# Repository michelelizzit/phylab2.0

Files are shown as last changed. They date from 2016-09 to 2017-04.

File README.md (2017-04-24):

# [PhyLab 2.0](https://lizzit.it/phylab)

More details available at https://lizzit.it/phylab

## General description
PhyLab is an open-source, modular system; it makes laboratory experience more interesting simplifying the understanding of science and physics.  
It has been created for school laboratories; it collects and processes experimental data at an incredibly high rate, makes plots and sends them to connected smartphones and other devices. It is composed of a series of collecting-transmitting Arduino-based units equipped with sensors; these deliver the data to the RaspberryPi-based main unit that produces real-time plots.  
This system can collect different types of data (temperature, humidity, speed…), limited only to the sensors available.

## Hardware
The main unit needs to be a RaspberryPI 1, 2 or 3.  
Each transmitting module sends data to the main unit either via an nRF24L01+ module or via USB.
The data is then saved on the main unit and sent to all the connected clients.  
The main unit can also act as a web server, and as a WiFi hotspot, this allows the system to be transported easily.  
It was designed for physics experiments at school, in a physics laboratory, and from that the name PhyLab 2.0
Each transmitting unit is usually based on an Arduino, connected with a sensor and an nRF24L01+ module but a transmitting unit can be made with any microcontroller and any sensor;  
### PhyLab PCBs
We designed two PhyLab PCBs, one that allows an nRF24L01+ module to be easily connected to the RaspberryPi and one that allows to easily build a transmitting unit; more details are available at https://lizzit.it/phylab/  





### Build it yourself
#### Main unit
For the main unit a RaspberryPI and an nRF24L01+ module are required; a DS1307 RTC is highly recommended since it allows the system to work even without wired internet connection; a reliable time, obtained either via NTP or via an RTC, is fundamental for the system to properly store data on the internal memory.  
  
The easiest way to build the main unit is to use a PhyLab 2.0 RaspberryPI module; it allows the nRF24L01+ to be easily connected to the RaspberryPI with no additional wiring needed.  
  
Building a unit without a PhyLab 2.0 RaspberryPI module is also possible.  
The RTC module shall be connected to I2C pins on the P1 header of the RaspberryPI.  
The nRF24L01+ module shall be connected to the RaspberryPI as shown on the diagram under /pcb; adding capacitor between VCC and GND may be useful to smooth current peaks of the nRF24L01+, which may cause system crashes.  
PhyLab 2.0 RaspberryPI module already includes capacitors between VCC and GND lines.  
#### Transmitting units
The easiest way to build a transmitting unit is to use a PhyLab 2.0 experiment module but a trasmitting unit can be also built easily with an Arduino, an nRF24L01+ module and a sensor.  
The nRF24L01+ shall be wired to the Arduino as follows:  

| nRF24L01+ pin  | Arduino pin |
| --- | --- |
| CE | pin 8 |
| CSN | pin 7 |
| MOSI | pin 11  |
| MISO | pin 12  |
| SCK | pin 13  |
| IRQ | N/C |
| VCC | 3.3v |
| GND | GND |

## Software
A pre-built image for RaspberryPI 3 is available, it includes all the software required on the server and in addition it creates a WiFi hotspot; this is the easiest way to set up a complete PhyLab 2.0 system.  
It is based on PhyLab OS, a minimal Linux distribution including a kernel build with just the modules required for PhyLab 2.0 to run.  
This allows PhyLab 2.0 to boot in just 5 seconds and to work out of the box with no setup needed.  
It is especially useful during physics lessons because it allows every student to see the plot and download the data from their smartphones.  

The pre-built image also includes a DNS and DHCP server (dnsmasq) that allows each device to connect easily and display the chart by going to http://phy.lab/  

Software for some experiments we have developed (humidity, acceleration and voltage) has been released, it can be uploaded either on a PhyLab 2.0 module or on an Arduino board.  

## Online demo

Demo version with random data available at: https://lizzit.it/phylab/demo/  
The demo version just shows the web interface, plotting random data, and is not connected to any sensor.






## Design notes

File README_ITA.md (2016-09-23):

# [PhyLab 2.0] (https://lizzit.it/phylab)

More details available at https://lizzit.it/phylab

##General description
PhyLab 2.0 è un sistema modulare e open source per l’acquisizione e l’elaborazione di dati; rende l'esperienza di laboratorio accattivante, facilita l'apprendimento della fisica laboratoriale.  
Acquisisce dati in maniera automatica, anche a frequenza elevata. È composto da unità di acquisizione-trasmissione (basate su Arduino) collegate a uno o più sensori; esse inviano i dati via wireless all’unità centrale (RaspberryPI) che li elabora in grafici. I dati e i grafici sono visualizzabili in tempo reale anche su smartphone. Può acquisire diversi tipi di dati (temperatura, umidità, forza…).  

##Hardware
L’unità centrale è basata su RaspberryPI versione 1, 2 o 3.
Ogni modulo trasmittente invia i dati all’unità centrale tramite un nRF24L01+ oppure tramite connessione USB.  
I dati vengono salvati sull’unità centrale e inviati a tutti dispositivi connessi.
L’unità centrale funziona anche da server web e come hotspot WiFi, questo consente al sistema un trasporto agevole e rapido.  
Il sistema è stato ideato per l’utilizzo nei laboratori scolastici di fisica, da questo deriva il nome PhyLab 2.0  
Le unità trasmittenti sono solitamente basate su Arduino, connesso a un modulo nRF24L01+ e a un sensore, ma qualunque microcontrollore può essere impiegato.  
###PhyLab PCBs
Abbiamo progettato due PhyLab PCB, uno per collegare facilmente un modulo nRF24L01+ al RaspberryPI, e uno che permette di costruire facilmente una unità trasmittente; ulteriori dettagli sono disponibili su https://lizzit.it/phylab  





##Software
Un immagine SD per RaspberryPI è disponibile al download; include tutto il software necessario al funzionamento di PhyLab 2.0 e inoltre crea una rete WiFi a cui collegarsi per visualizzare il grafico.  
L'immagine è basata su PhyLab OS, sistema operativo Linux che include un kernel compilato con i soli moduli necessari a far funzionare PhyLab 2.0  
Questo consente a PhyLab 2.0 di avviarsi in appena 5 secondi ed essere subito operativo, senza alcuna configurazione richiesta.  
È particolarmente utile durante le lezioni di fisica perchè consente a ogni studente di ricevere i dati sul proprio smartphone, visualizzarli sul grafico e scaricarli in formato CSV.  
Il software per alcune unità trasmittenti che abbiamo sviluppato (umidità, temperatura, accelerazione, distanza, tensione, corrente...) verrà rilasciato a breve.  
L’immagine SD include inoltre un server DNS e un server DHCP (dnsmasq) che permette a ogni dispositivo di collegarsi facilmente e visualizzare il grafico andando su http://phy.lab/  

##Demo online

Una versione dimostrativa online è disponibile su: https://lizzit.it/phylab/demo/  
La versione demo mostra solamente l’interfaccia web, con dati casuali, senza essere connessa ad alcun sensore.  






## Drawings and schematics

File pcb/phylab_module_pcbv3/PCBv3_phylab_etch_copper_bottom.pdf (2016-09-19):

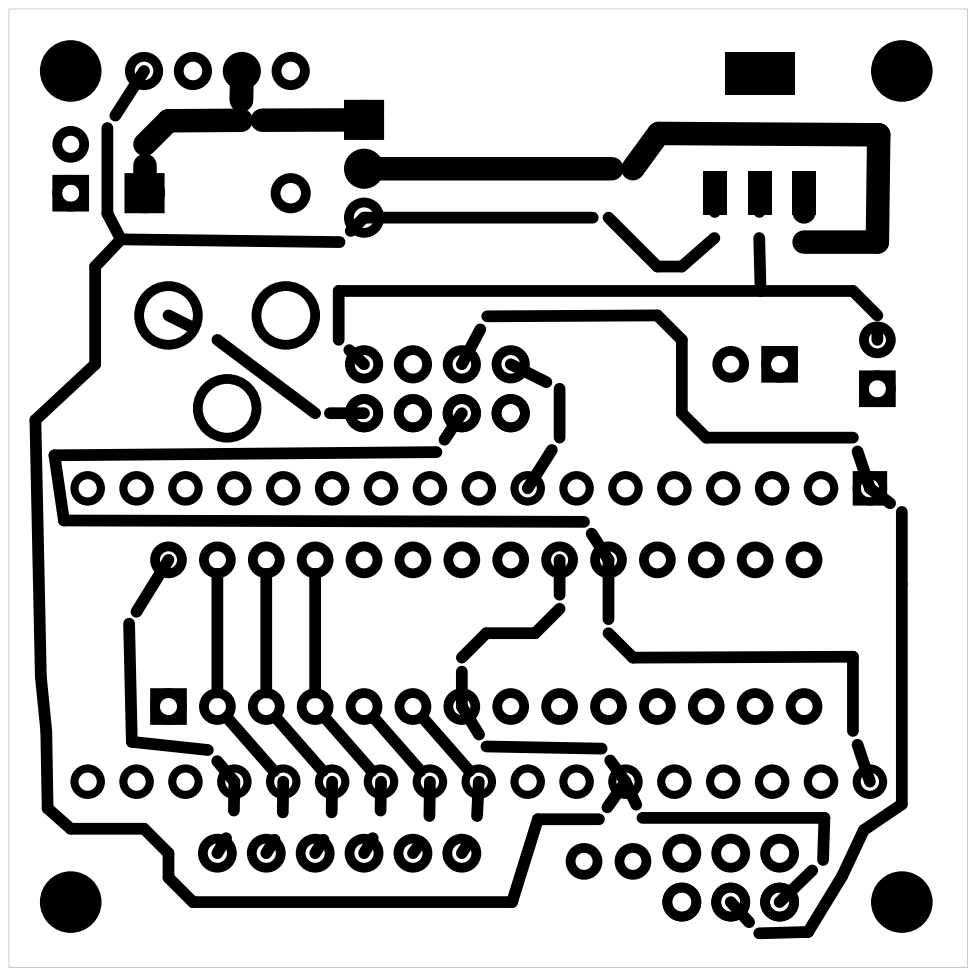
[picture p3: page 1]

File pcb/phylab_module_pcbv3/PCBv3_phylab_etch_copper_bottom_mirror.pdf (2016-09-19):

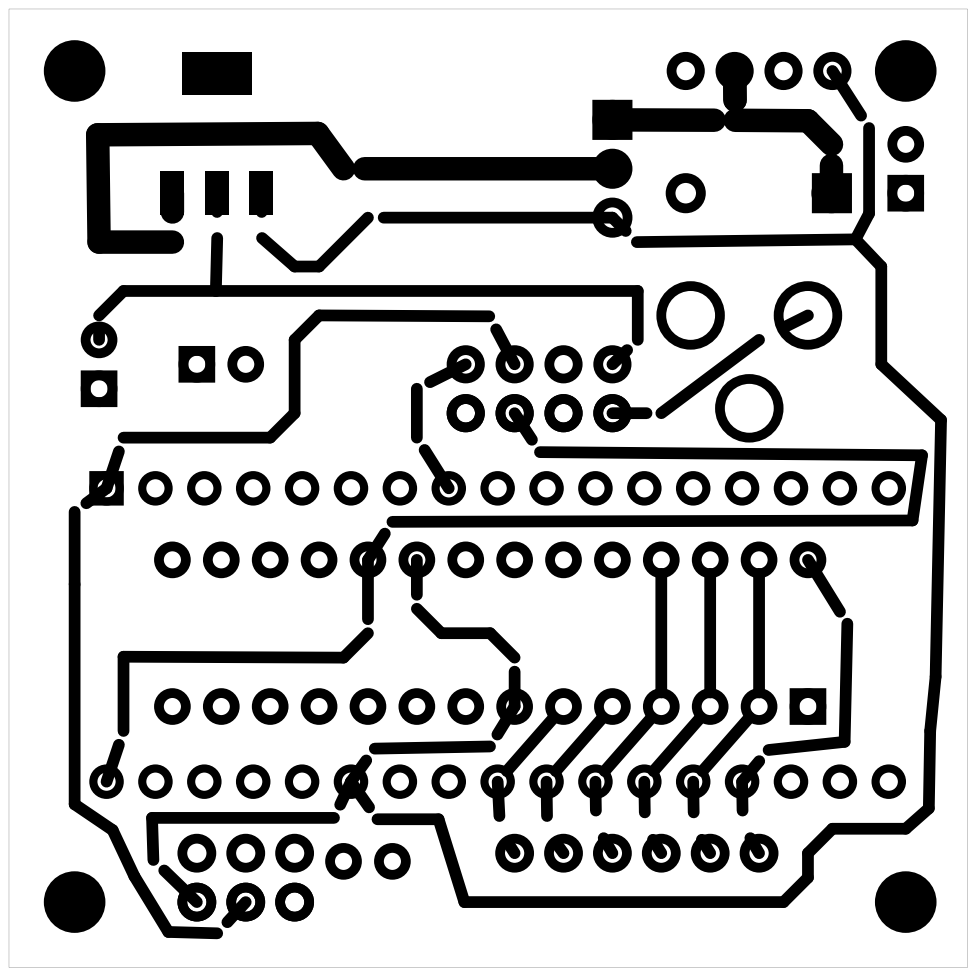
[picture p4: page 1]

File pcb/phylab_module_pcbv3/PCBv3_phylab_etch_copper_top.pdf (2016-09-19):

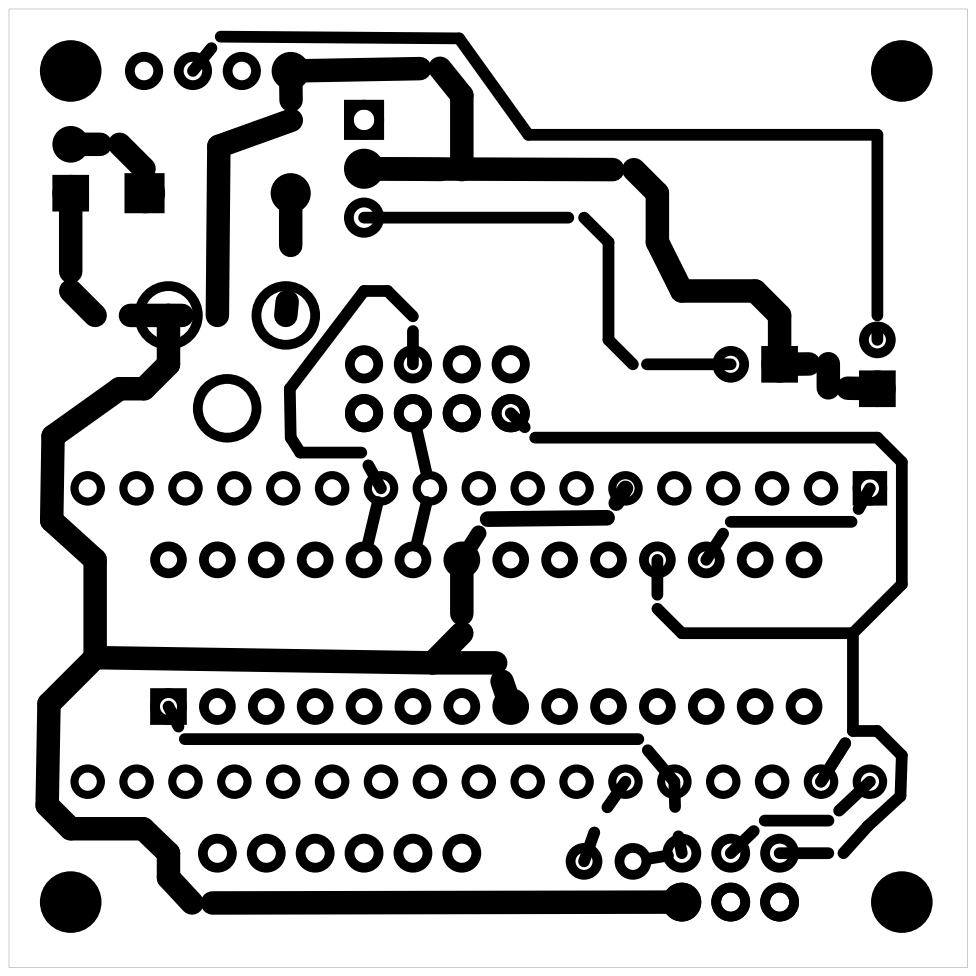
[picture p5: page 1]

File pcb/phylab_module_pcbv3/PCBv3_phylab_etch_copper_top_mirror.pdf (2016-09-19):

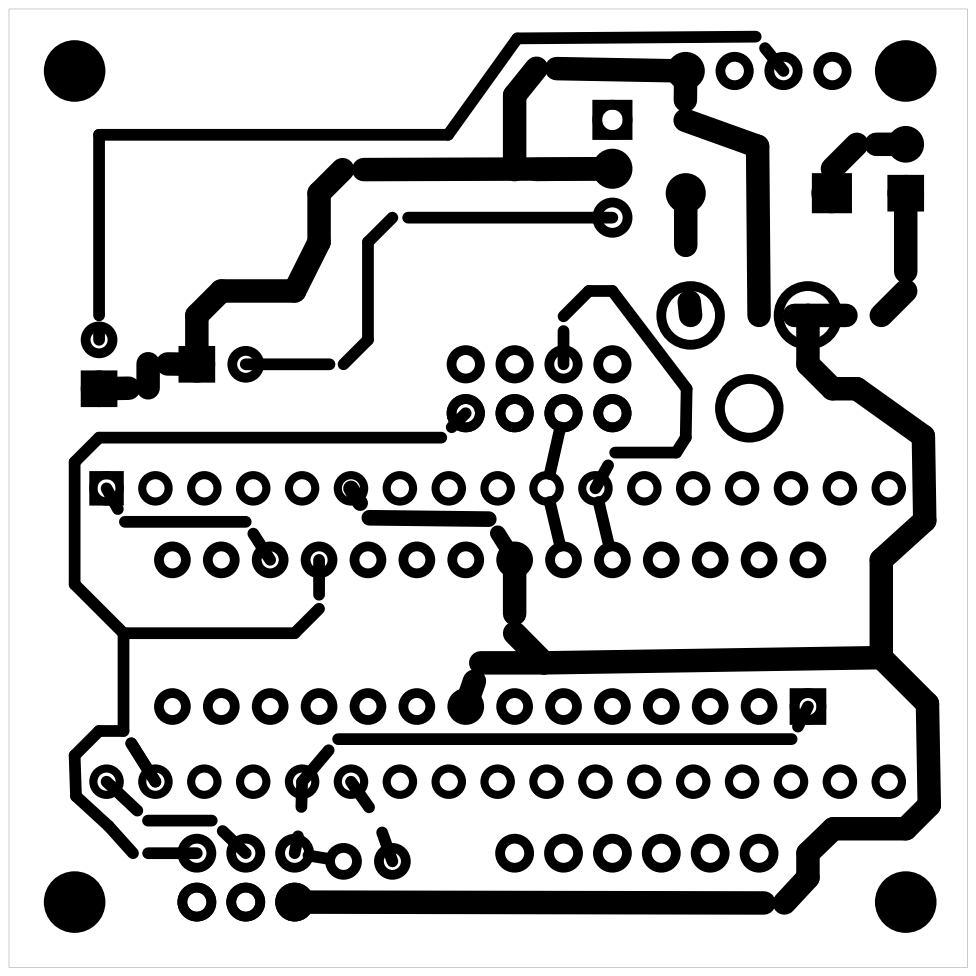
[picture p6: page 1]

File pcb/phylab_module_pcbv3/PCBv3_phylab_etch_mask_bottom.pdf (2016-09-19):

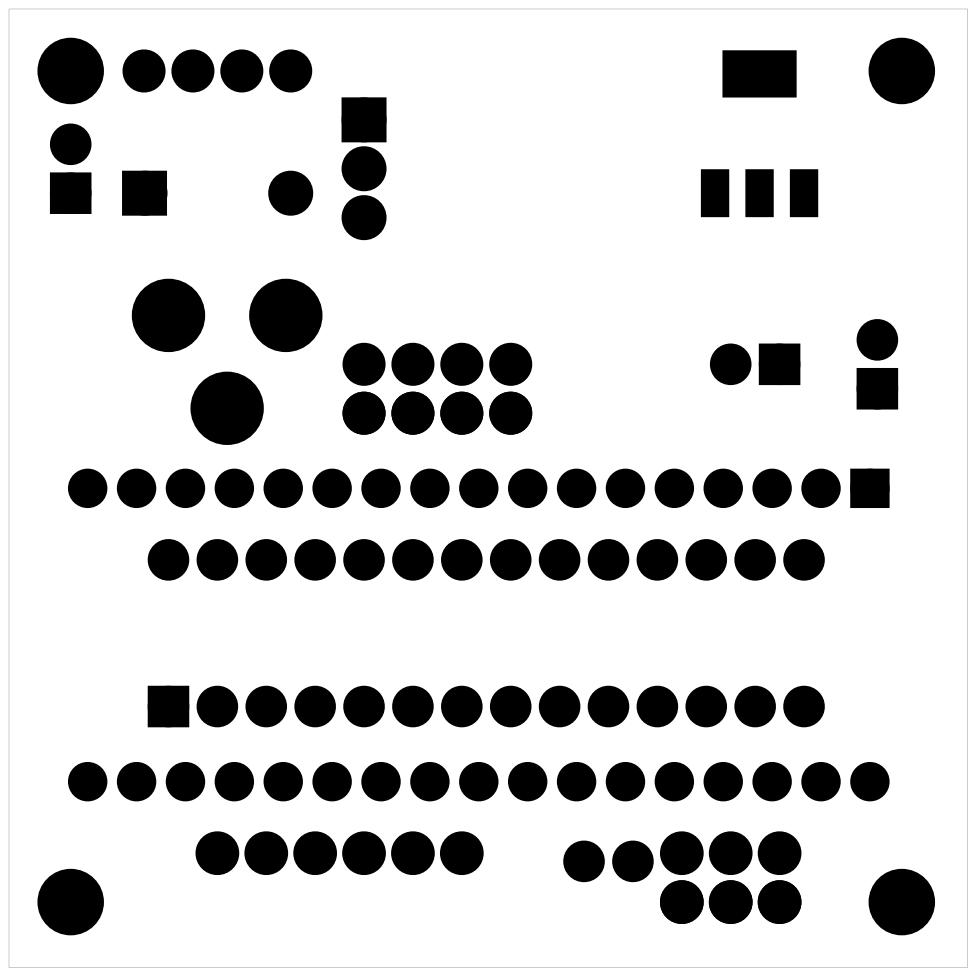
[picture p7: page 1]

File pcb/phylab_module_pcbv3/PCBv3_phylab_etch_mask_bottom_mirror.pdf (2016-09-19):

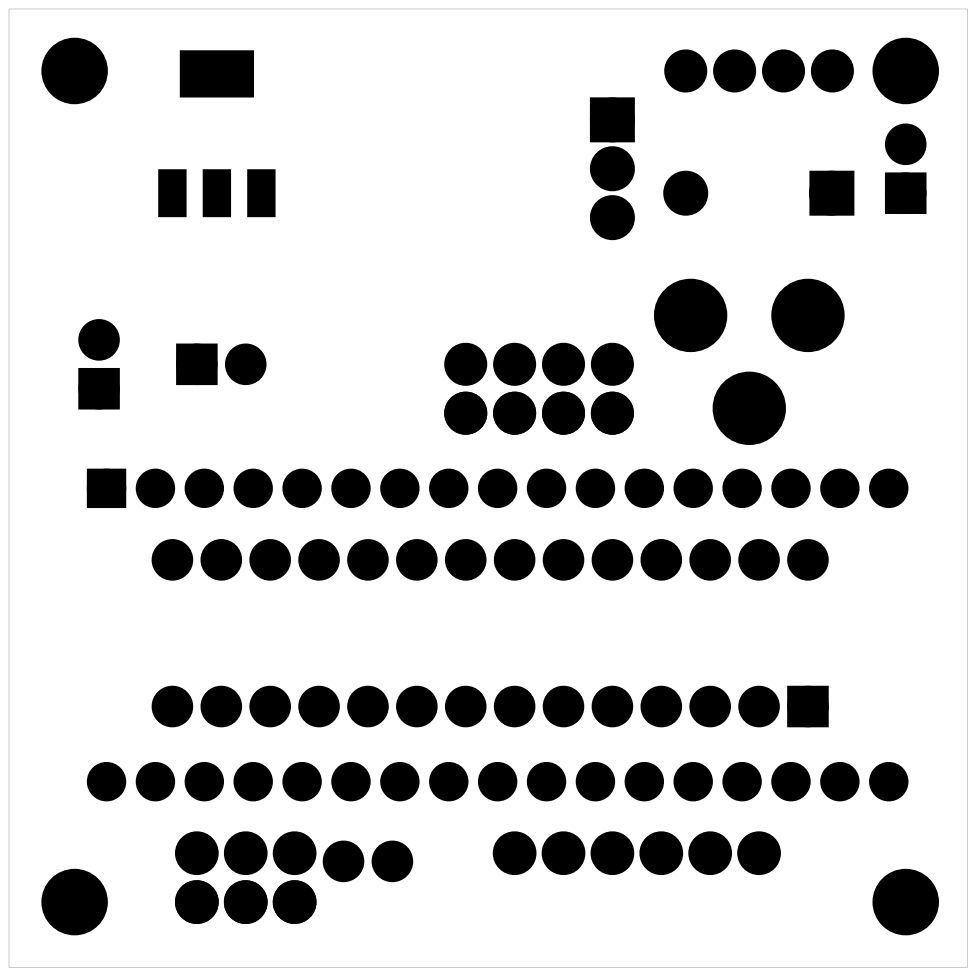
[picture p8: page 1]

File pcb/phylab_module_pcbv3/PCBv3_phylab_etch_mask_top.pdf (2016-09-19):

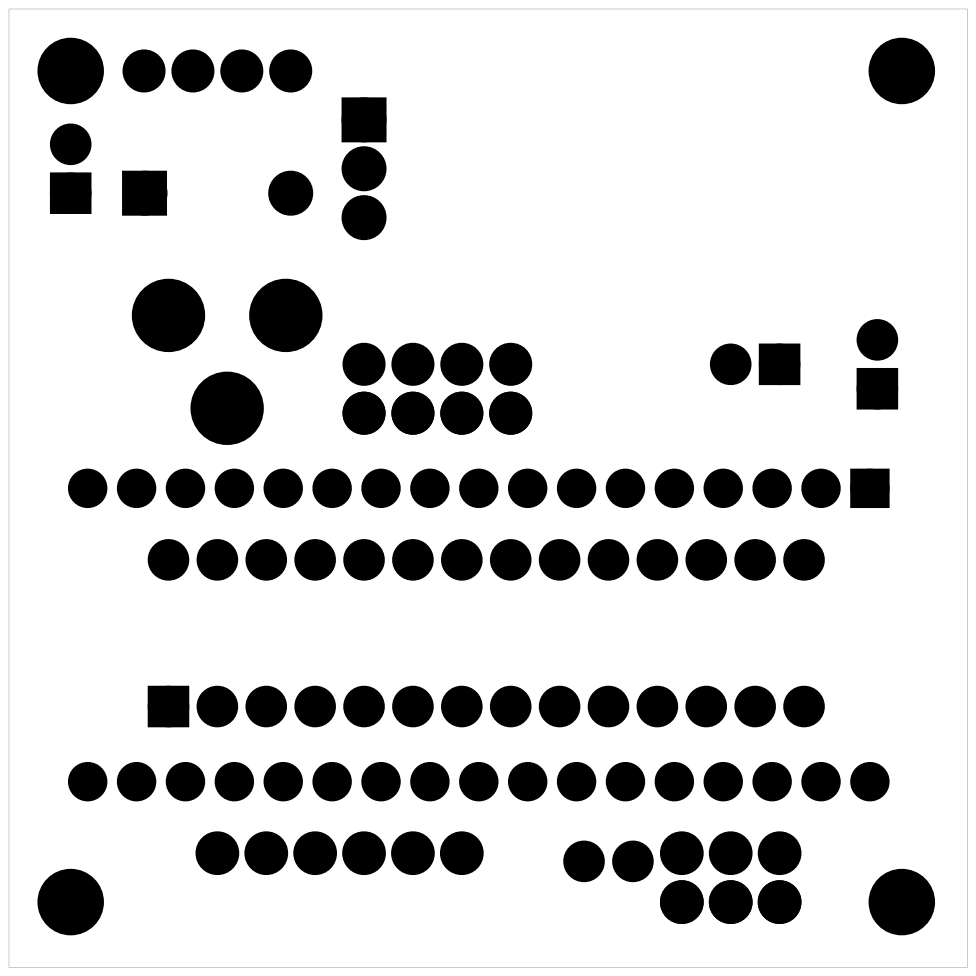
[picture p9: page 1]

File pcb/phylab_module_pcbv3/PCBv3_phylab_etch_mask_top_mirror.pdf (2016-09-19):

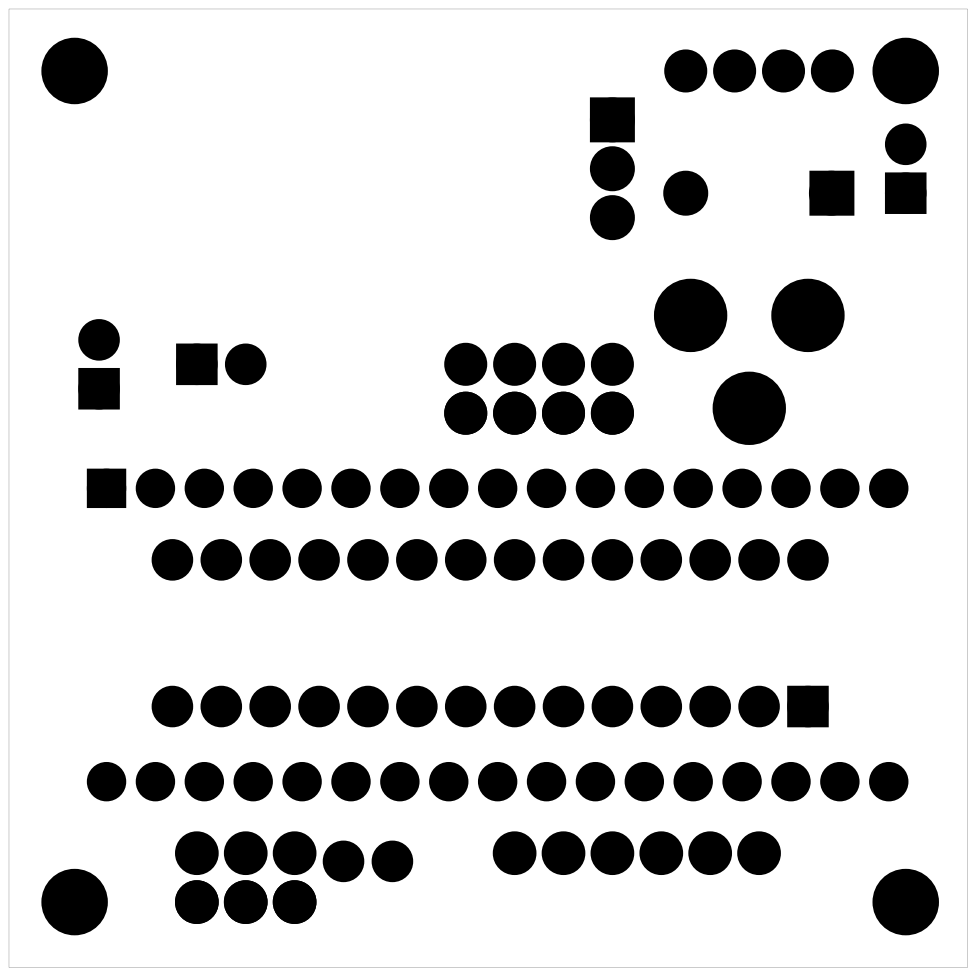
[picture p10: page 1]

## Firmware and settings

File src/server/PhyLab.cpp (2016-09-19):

/*
 *
 *	PhyLab 2.0 - https://lizzit.it/phylab
 *	Author: Michele Lizzit - lizzit.it
 *
 *	Updates: 	19/9/2016
 *				26/7/2016
 *				25/8/2015
 *  			15/4/2015
 *
 *
 *  Copyright (C) 2016  Michele Lizzit
 *
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
 *  You should have received a copy of the GNU Affero General Public License
 *  along with this program.  If not, see <http://www.gnu.org/licenses/>.
 */

#include <stdio.h>
#include <stdint.h>
#include "bcm2835.h"
#include <stdbool.h>
#include <stdlib.h>
#include <sys/time.h>
#include <time.h>
#include <string.h>
#include <fcntl.h>
#include <errno.h>
#include <termios.h>
#include <unistd.h>
#include <errno.h>
#include <thread>
#include <execinfo.h>

#include "nRF24L01.cpp"

using namespace std;

char radiationValue[] = { '0', '0', '0', '0', '0', '\0' };
char temperatureValue[] = { '0', '0', '0', '0', '0', '\0' };
char accelerationValue[] = { '0', '0', '0', '0', '0', '\0' };
char timeValue[] = { '0', '0', '0', '0', '0', '\0' };
char distanceValue[] = { '0', '0', '0', '0', '0', '\0' };
char humidityValue[] = { '0', '0', '0', '0', '0', '\0' };
char voltageValue[] = { '0', '0', '0', '0', '0', '\0' };
char lampVoltageValue[] = { '0', '0', '0', '0', '0', '\0' };
char lampCurrentValue[] = { '0', '0', '0', '0', '0', '\0' };
bool saveRadiation = true;
bool saveTemperature = true;
bool saveAcceleration = true;
bool saveTime = true;
bool saveDistance = true;
bool saveHumidity = true;
bool saveVoltage = true;
bool databaseAccessible = true;
const int numSensors = 7;
const int START_DATABASE_SIZE = 5;
FILE* dataFile[numSensors];
char dataFileName[numSensors][25];
uint64_t* databaseTime[numSensors];
int* databaseValues[numSensors];
int currentDatabaseSize[numSensors];
int currentDatabasePos[numSensors];

const int numUSB = 3;
int serialModule[numUSB];
bool serialActive[numUSB];
char serNames[numUSB][13];

unsigned char serialBuffer[numUSB][256];
int bufferPos[numUSB];

const bool DEBUG = true;

void printDebugLineStart() {
	if (DEBUG)
		printf("[phylab] ");
}

void printDebugLineEnd() {
	if (DEBUG) {
		printf("\n");
		fflush(stdout);
	}
}

void segFaultHandler(int sigNum) {
	printDebugLineStart();
	if (DEBUG)
		printf("Segmentation fault detected");
	printDebugLineEnd();

	void *buf[10];
	size_t size = backtrace(buf, 10);
	fprintf(stderr, "Error: signal %d:\n", sigNum);
	backtrace_symbols_fd(buf, size, STDERR_FILENO);

	exit(1);
}

void createSerialList() {
	strcpy(serNames[0], "/dev/ttyACM0\0");
	strcpy(serNames[1], "/dev/ttyAMA0\0");
	strcpy(serNames[2], "/dev/ttyUSB0\0");
}

void createFileNamesList() { //Gli array hanno lunghezza 25!!
	strcpy(dataFileName[0], "/mnt/plab_data/time.plab\0");
	strcpy(dataFileName[1], "/mnt/plab_data/temp.plab\0");
	strcpy(dataFileName[2], "/mnt/plab_data/humd.plab\0");
	strcpy(dataFileName[3], "/mnt/plab_data/dist.plab\0");
	strcpy(dataFileName[4], "/mnt/plab_data/accl.plab\0");
	strcpy(dataFileName[5], "/mnt/plab_data/volt.plab\0");
	strcpy(dataFileName[6], "/mnt/plab_data/radt.plab\0");
}

void createDatabase() {
	for (int cnt = 0; cnt < numSensors; cnt++) {
		databaseTime[cnt] = new uint64_t[START_DATABASE_SIZE];
		databaseValues[cnt] = new int[START_DATABASE_SIZE];
		currentDatabasePos[cnt] = 0;
		currentDatabaseSize[cnt] = START_DATABASE_SIZE;
	}
}

void expandDatabase(int numDatabase) {
	int newDatabaseSize = currentDatabaseSize[numDatabase] * 2;
	uint64_t* tmpT;
	int* tmpD;

	//alloca spazio per il nuovo database
	tmpT = new uint64_t[newDatabaseSize];
	tmpD = new int[newDatabaseSize];
	
	//copia il vecchio database nel nuovo
	for (int cnt = 0; cnt < currentDatabaseSize[numDatabase]; cnt++) {
		tmpT[cnt] = databaseTime[numDatabase][cnt];
		tmpD[cnt] = databaseValues[numDatabase][cnt];
	}
	
	//libera lo spazio dei vecchi array
	delete databaseTime[numDatabase];
	delete databaseValues[numDatabase];
	
	//copia i puntatori
	databaseTime[numDatabase] = tmpT;
	databaseValues[numDatabase] = tmpD;

	currentDatabaseSize[numDatabase] = newDatabaseSize;
}

void clearDatabase(int numDatabase) { //!!!!funzione eseguita mentre il thread scrive
	int newDatabaseSize = START_DATABASE_SIZE;
	uint64_t* tmpT;
	int* tmpD;
	uint64_t* tmpT2;
	int* tmpD2;

	//chiede al thread di non usare i file del db
	databaseAccessible = false;

	//alloca spazio per il nuovo database
	tmpT = new uint64_t[newDatabaseSize];
	tmpD = new int[newDatabaseSize];

	//resetta la variabile posizione
	currentDatabasePos[numDatabase] = 0;
	
	//copia i vecchi puntatori
	tmpT2 = databaseTime[numDatabase];
	tmpD2 = databaseValues[numDatabase];

	//copia i nuovi puntatori
	databaseTime[numDatabase] = tmpT;
	databaseValues[numDatabase] = tmpD;

	//aggiorna la dimensione del database
	currentDatabaseSize[numDatabase] = newDatabaseSize;

	//libera lo spazio dei vecchi array
	delete tmpT2;
	delete tmpD2;
	
	//cancella il file relativo al database
	fclose(dataFile[numDatabase]);
	dataFile[numDatabase] = fopen(dataFileName[numDatabase], "w+");

	//ora i file sono di nuovo accessibili
	databaseAccessible = true;
}

void loadDatabaseFromFiles() {
	int valuesCounter = 0;
	for (int cnt = 0; cnt < numSensors; cnt++) {
		int tmpScanRes = 1;
		rewind(dataFile[cnt]);
		while ((tmpScanRes != EOF) && (tmpScanRes != 0)) { 
			uint64_t tmpTimeVal;
			int tmpDataVal;
			//tmpScanRes = fscanf(dataFile[cnt], "%llu%d", &tmpTimeVal, &tmpDataVal);

    		char tmpLine[16];
    		if (!fgets(tmpLine, 23, dataFile[cnt])) break;
    		tmpScanRes = sscanf(tmpLine, "%llu\t%d", &tmpTimeVal, &tmpDataVal);

			
			//printf("D %llu %d", tmpTimeVal, tmpDataVal);
			if (tmpScanRes == EOF) {
				//printf("T %s;", dataFileName[cnt]);
				break;
			}
			else if (tmpScanRes == 2) {
				//printf("R%d", tmpScanRes);
				if (currentDatabasePos[cnt] + 2 >= currentDatabaseSize[cnt])
					expandDatabase(cnt);
				//printf("E%d", tmpScanRes);

				databaseTime[cnt][currentDatabasePos[cnt]] = tmpTimeVal;
				databaseValues[cnt][currentDatabasePos[cnt]] = tmpDataVal;
				currentDatabasePos[cnt]++;

				valuesCounter++;
			}
			else {
				printf("Corrupted database\n");
				fflush(stdout);
			}
		}
	}

	printf("Successfully loaded %d values from database\n", valuesCounter);
}

void openFiles() {
	createFileNamesList();
	for (int cnt = 0; cnt < numSensors; cnt++)
		dataFile[cnt] = fopen(dataFileName[cnt], "a+");

	for (int cnt = 0; cnt < numSensors; cnt++) {
		if(dataFile[cnt] == NULL) {
    		printf("Error opening database file: %s\n", strerror(errno));
    		exit(1);
		}
	}
}

void closeFiles() {
	for (int cnt = 0; cnt < numSensors; cnt++)
		fclose(dataFile[cnt]);
}

int initSerial(char* serialName) { 
	createSerialList();

	int ser = open(serialName, O_RDWR | O_NOCTTY | O_NDELAY);

	if (ser == -1 ) return -1;

	struct termios options;
	tcgetattr(ser, &options);
	options.c_cflag = B57600 | CS8 | CLOCAL | CREAD; //baud rate
	options.c_iflag = IGNBRK | IGNPAR;
	options.c_oflag = 0;
	options.c_lflag = 0;
	tcflush(ser, TCIFLUSH);
	tcsetattr(ser, TCSANOW, &options);

	usleep(20000);
	return ser;
}

void serialWrite(int ser, char* data, int len) {
	write(ser, data, len);
}

int serialRead(int ser, unsigned char* data, int len) {
	return read(ser, (void*)data, len);
}

void resetBufferPos() {
	for (int cnt = 0; cnt < numUSB; cnt++)
		bufferPos[numUSB] = 0;
}

void initAllSerial() {
	resetBufferPos();

	for (int cnt = 0; cnt < numUSB; cnt++)
		serialModule[cnt] = initSerial(serNames[cnt]);

	for (int cnt = 0; cnt < numUSB; cnt++) {
		if (serialModule[cnt] < 0) {
			serialActive[cnt] = false;
		}
		else {
			serialActive[cnt] = true;
			printf("Successfully opened serial %s\n", serNames[cnt]);
		}
	}
}

bool devExists(char* devPath) {
	if( access( devPath, F_OK ) != -1 )
		return true;

	return false;
}

void refreshActiveSerialList() {
	for (int cnt = 0; cnt < numUSB; cnt++) {
		if (!serialActive[cnt]) {
			if (devExists(serNames[cnt])) {
				printf("New serial device found\n");
				int tmpSerID = initSerial(serNames[cnt]);
				if (tmpSerID >= 0) {
					serialModule[cnt] = tmpSerID;
					serialActive[cnt] = true;
				}
			}
		}/*
		else { //if serial is active check if it still exists
			if (!devExists(serNames[cnt])) {
				printf("A%s\n", serNames[cnt]);
				serialActive[cnt] = false;
				close(serialModule[cnt]);
			}

		}*/
	}
}

void start() {
	bcm2835_gpio_fsel(CE_PIN, BCM2835_GPIO_FSEL_OUTP);

	bcm2835_spi_begin();
	
	bcm2835_spi_setChipSelectPolarity(BCM2835_SPI_CS0, 0);
	
	bcm2835_spi_setClockDivider(BCM2835_SPI_CLOCK_DIVIDER_128); //nRF24L01+ maximum is 10Mhz
	bcm2835_spi_setDataMode(BCM2835_SPI_MODE0);
	bcm2835_spi_chipSelect(BCM2835_SPI_CS0);

	bcm2835_gpio_write(CE_PIN, LOW);
	initializeNRF24L01();
	bcm2835_gpio_write(CE_PIN, HIGH);

	initAllSerial();
}

void parseTemperature(char data1, char data2, char data3, char data4, char data5) {
	temperatureValue[0] = data5;
	temperatureValue[1] = data4;
	temperatureValue[2] = data3;
	temperatureValue[3] = data2;
	temperatureValue[4] = data1;

	char* tmp;
	int tmpTempVal = (int)strtol(temperatureValue, &tmp, 10);
	tmpTempVal -= 323;
	tmpTempVal *= 24;
	char tmpStrVal[10] = {'0', '0', '0', '0', '0', '0', '0', '0', '0', '0'};
	sprintf(tmpStrVal, "%d", tmpTempVal);
	temperatureValue[0] = tmpStrVal[0];
	temperatureValue[1] = tmpStrVal[1];
	temperatureValue[2] = tmpStrVal[2];
	temperatureValue[3] = tmpStrVal[3];
	temperatureValue[4] = tmpStrVal[4];

	struct timeval tempOra;
	gettimeofday(&tempOra, NULL);
	uint64_t tempOraus = (uint64_t)(tempOra.tv_sec) * 1000 + (uint64_t)(tempOra.tv_usec / 1000);

	if (saveAcceleration) {
		int currentSensorID = 1;
		//printf("A");
		if (databaseAccessible)
			fprintf(dataFile[currentSensorID], "%llu\t%d\n", tempOraus, tmpTempVal);
		if (currentDatabasePos[currentSensorID] >= currentDatabaseSize[currentSensorID] - 2)
			expandDatabase(currentSensorID);
		char* tmp;
		databaseValues[currentSensorID][currentDatabasePos[currentSensorID]] = tmpTempVal;
		databaseTime[currentSensorID][currentDatabasePos[currentSensorID]] = tempOraus;
		currentDatabasePos[currentSensorID]++;
	}

	//printf("Temperature: %f\n", data5);
}

void parseRadiation(char data1, char data2, char data3, char data4, char data5) {
	radiationValue[0] = data1;
	radiationValue[1] = data2;
	radiationValue[2] = data3;
	radiationValue[3] = data4;
	radiationValue[4] = data5;

	printf("Radiation: %f\n", radiationValue);
}

void parseLampCurrent(char data1, char data2, char data3, char data4, char data5) {
	lampCurrentValue[0] = data1;
	lampCurrentValue[1] = data2;
	lampCurrentValue[2] = data3;
	lampCurrentValue[3] = data4;
	lampCurrentValue[4] = data5;

	printDebugLineStart();
	if (DEBUG)
		printf("[data received] Lamp current: %s", lampCurrentValue);
	printDebugLineEnd();
}

void parseLampVoltage(char data1, char data2, char data3, char data4, char data5) {
	lampVoltageValue[0] = data1;
	lampVoltageValue[1] = data2;
	lampVoltageValue[2] = data3;
	lampVoltageValue[3] = data4;
	lampVoltageValue[4] = data5;

	printDebugLineStart();
	if (DEBUG)
		printf("[data received] Lamp voltage: %s", lampVoltageValue);
	printDebugLineEnd();
}

void parseAcceleration(char data1, char data2, char data3, char data4, char data5) {
	accelerationValue[0] = data1;
	accelerationValue[1] = data2;
	accelerationValue[2] = data3;
	accelerationValue[3] = data4;
	accelerationValue[4] = data5;

	char* tmp;
	int tmpAccVal = (int)strtol(accelerationValue, &tmp, 10);
	tmpAccVal -= 323;
	tmpAccVal *= 24;
	char tmpStrVal[10] = {'0', '0', '0', '0', '0', '0', '0', '0', '0', '0'};
	sprintf(tmpStrVal, "%d", tmpAccVal);
	accelerationValue[0] = tmpStrVal[0];
	accelerationValue[1] = tmpStrVal[1];
	accelerationValue[2] = tmpStrVal[2];
	accelerationValue[3] = tmpStrVal[3];
	accelerationValue[4] = tmpStrVal[4];

	struct timeval tempOra;
	gettimeofday(&tempOra, NULL);
	uint64_t tempOraus = (uint64_t)(tempOra.tv_sec) * 1000 + (uint64_t)(tempOra.tv_usec / 1000);

	if (saveAcceleration) {
		int currentSensorID = 4;
		//printf("A");
		if (databaseAccessible)
			fprintf(dataFile[currentSensorID], "%llu\t%d\n", tempOraus, tmpAccVal);
		if (currentDatabasePos[currentSensorID] >= currentDatabaseSize[currentSensorID] - 2)
			expandDatabase(currentSensorID);
		char* tmp;
		databaseValues[currentSensorID][currentDatabasePos[currentSensorID]] = tmpAccVal;
		databaseTime[currentSensorID][currentDatabasePos[currentSensorID]] = tempOraus;
		currentDatabasePos[currentSensorID]++;
	}

	//char* tmp;
	//printf("A%d", strtol(accelerationValue, &tmp, 10));
}

void parseDistance(char data1, char data2, char data3, char data4, char data5) {
	distanceValue[0] = data1;
	distanceValue[1] = data2;
	distanceValue[2] = data3;
	distanceValue[3] = data4;
	distanceValue[4] = data5;
}

void parseHumidity(char data1, char data2, char data3, char data4, char data5) {
	humidityValue[0] = data1;
	humidityValue[1] = data2;
	humidityValue[2] = data3;
	humidityValue[3] = data4;
	humidityValue[4] = data5;
	
	struct timeval tempOra;
	gettimeofday(&tempOra, NULL);
	uint64_t tempOraus = (uint64_t)(tempOra.tv_sec) * 1000 + (uint64_t)(tempOra.tv_usec / 1000);

	if (saveHumidity) {
		int currentSensorID = 2;
		if (databaseAccessible)
			fprintf(dataFile[currentSensorID], "%llu\t%c%c%c%c%c\n", tempOraus, data1, data2, data3, data4, data5);
		if (currentDatabasePos[currentSensorID] >= currentDatabaseSize[currentSensorID] - 2)
			expandDatabase(currentSensorID);
		char* tmp;
		databaseValues[currentSensorID][currentDatabasePos[currentSensorID]] = (int)strtol(humidityValue, &tmp, 10);
		databaseTime[currentSensorID][currentDatabasePos[currentSensorID]] = tempOraus;
		currentDatabasePos[currentSensorID]++;
	}

	//printf("Humidity: %s\n", humidityValue);
}
void parseVoltage(char data1, char data2, char data3, char data4, char data5) {
	voltageValue[0] = data1;
	voltageValue[1] = data2;
	voltageValue[2] = data3;
	voltageValue[3] = data4;
	voltageValue[4] = data5;

	char* tmp;
	int tmpVolVal = (int)strtol(voltageValue, &tmp, 10);
	tmpVolVal -= 323;
	tmpVolVal *= 24;
	char tmpStrVal[10] = {'0', '0', '0', '0', '0', '0', '0', '0', '0', '0'};
	sprintf(tmpStrVal, "%d", tmpVolVal);
	voltageValue[0] = tmpStrVal[0];
	voltageValue[1] = tmpStrVal[1];
	voltageValue[2] = tmpStrVal[2];
	voltageValue[3] = tmpStrVal[3];
	voltageValue[4] = tmpStrVal[4];

	struct timeval tempOra;
	gettimeofday(&tempOra, NULL);
	uint64_t tempOraus = (uint64_t)(tempOra.tv_sec) * 1000 + (uint64_t)(tempOra.tv_usec / 1000);

	if (saveAcceleration) {
		int currentSensorID = 5;
		//printf("A");
		if (databaseAccessible)
			fprintf(dataFile[currentSensorID], "%llu\t%d\n", tempOraus, tmpVolVal);
		if (currentDatabasePos[currentSensorID] >= currentDatabaseSize[currentSensorID] - 2)
			expandDatabase(currentSensorID);
		char* tmp;
		databaseValues[currentSensorID][currentDatabasePos[currentSensorID]] = tmpVolVal;
		databaseTime[currentSensorID][currentDatabasePos[currentSensorID]] = tempOraus;
		currentDatabasePos[currentSensorID]++;
	}

	//printf("Voltage: %s\n", voltageValue);
}

void parsePacket(char packetContent[]) {
	/*for (int cnt = 2; cnt + 1 < 10; cnt++) dati[cnt] = packetContent.charAt(cnt);
	//char mittente = dati[0];
	//char destinatario = dati[1];*/

	char tipoDati = packetContent[2]; // a = data b = other
	
	/*char tipoDati2 = ' ';
	if (tipoDati == 'b') tipoDati2 = dati[3];
	if ((tipoDati == 'b') && (tipoDati2 == 'a')) sendKeepAliveReply();*/

	char tipoSensore = ' ';
	if (tipoDati == 'a') { 
		tipoSensore = packetContent[3];   //1 = TEMPERATURA 2 = ACCELERAZIONE 3 = TEMPO
		if (tipoSensore == '1') parseTemperature(packetContent[4], packetContent[5], packetContent[6], packetContent[7], packetContent[8]);
		else if (tipoSensore == '2') parseAcceleration(packetContent[4], packetContent[5], packetContent[6], packetContent[7], packetContent[8]);
		//else if (tipoSensore == '3') parseTime(packetContent[4], packetContent[5], packetContent[6], packetContent[7], packetContent[8]);
		else if (tipoSensore == '4') parseDistance(packetContent[4], packetContent[5], packetContent[6], packetContent[7], packetContent[8]);
		else if (tipoSensore == '5') parseRadiation(packetContent[4], packetContent[5], packetContent[6], packetContent[7], packetContent[8]);
		else if (tipoSensore == '6') parseHumidity(packetContent[4], packetContent[5], packetContent[6], packetContent[7], packetContent[8]);
		else if (tipoSensore == '7') parseVoltage(packetContent[4], packetContent[5], packetContent[6], packetContent[7], packetContent[8]);
		else if (tipoSensore == 'A') parseLampVoltage(packetContent[4], packetContent[5], packetContent[6], packetContent[7], packetContent[8]);
		else if (tipoSensore == 'B') parseLampCurrent(packetContent[4], packetContent[5], packetContent[6], packetContent[7], packetContent[8]);
	}
	//System.out.println("tipoDati: " + tipoDati);
	//System.out.println("tipoSensore: " + tipoSensore);
}

bool isValidPacket(char packetContent[]) {
	
	if (packetContent[0] != 'a') {
		printf(",");
		fflush(stdout);
		return false;
	}
	else if (packetContent[9] != '!') {
		printf(";");
		fflush(stdout);
		return false;
	}
	return true;
}

void acquisisciDati(char messaggio[10]) {
	//printf("*");
    fflush(stdout);
	if (isValidPacket(messaggio)) {
    	fflush(stdout);
		parsePacket(messaggio);
		messaggio[9] = '*';
		messaggio[0] = '*';
	}
	else fprintf(stderr, ";");
}

void deleteBufferElem(int bufferIndex, int shiftNum) {
	for (int cnt = shiftNum; cnt < bufferPos[bufferIndex]; cnt++)
		serialBuffer[bufferIndex][cnt - shiftNum] = serialBuffer[bufferIndex][cnt];
	bufferPos[bufferIndex] -= shiftNum;
}

void acquisisciDatiSeriale() {
	int packetLength = 10;

	//controlla se nel buffer c'è un pacchetto valido
	for (int currentSerial = 0; currentSerial < numUSB; currentSerial++) {
		for (int cnt = 0; cnt < bufferPos[currentSerial] - (packetLength - 3); cnt++) {
			if ((serialBuffer[currentSerial][cnt] == 'a') and
				(serialBuffer[currentSerial][cnt + 1] == 'b') and
				(serialBuffer[currentSerial][cnt + 2] == 'a') and
				(serialBuffer[currentSerial][cnt + 9] == '!')) {

				//se c'è un pacchetto valido lo estrae e lo copia in un array
				char tmpPacket[packetLength];
				for (int cnt2 = 0; cnt2 < packetLength; cnt2++)
					tmpPacket[cnt2] = serialBuffer[currentSerial][cnt + cnt2];

				//il pacchetto viene processato
				acquisisciDati(tmpPacket);

				//una volta processato il pacchetto rimuove
				//dal buffer il pacchetto e i byte precendenti
				deleteBufferElem(currentSerial, cnt + packetLength);
			}
		}

		//elimina i primi elementi del buffer per riportarlo a massimo 9 elementi
		//aggiorna bufferPos
		if (bufferPos[currentSerial] >= packetLength) {
			int shiftNum = bufferPos[currentSerial] - (packetLength - 1);
			deleteBufferElem(currentSerial, shiftNum);
		}
	}
}

int numPacket = 0;

void checkDataAvailable() {
	if (packetAvail()) {
			char data[10];
			getNRFpacket(data);
			//printf("Data: %c%c\n", data[0], data[9]);
			acquisisciDati(data);
			
			//printf(".");
			//fflush(stdout);
			/*numPacket++;
			if (numPacket >= 100) {
				numPacket = 0;

				gettimeofday(&tempOra, NULL);
				int tempOraus = (tempOra.tv_sec) * 1000000 + (tempOra.tv_usec);

				printf("AS100 %d\n", (tempOraus - tempPacchettous));

				gettimeofday(&tempPacchetto, NULL);
				tempPacchettous = (tempPacchetto.tv_sec) * 1000000 + (tempPacchetto.tv_usec) ;
			}*/
		}
		unsigned char tmpBufferR[256];
		for (int cnt = 0; cnt < numUSB; cnt++) {
			if (serialActive[cnt]) {
				short numByteR = serialRead(serialModule[cnt], tmpBufferR , 255);
				if (numByteR > 0) {
					for (int cnt2 = 0; cnt2 < numByteR; cnt2++) {
						//printf("%c", tmpBufferR[cnt2]);
						serialBuffer[cnt][bufferPos[cnt]] = tmpBufferR[cnt2];
						bufferPos[cnt]++;
					}
					acquisisciDatiSeriale();
				}
			}
		}
		numPacket++;
		if (numPacket >= 50000) { //called every 50000 loops
			numPacket = 0;
			refreshActiveSerialList();
			/*for (int cnt = 0; cnt < currentDatabasePos[4]; cnt++)
				printf("%d, ", databaseValues[4][cnt]);
			printf("\n");*/
		}
}


#include "websocket.cpp"


int force_exit = 0;

void sigHandler(int signal) {
	force_exit = 1;
}

void checkDataThread() {
	while (!force_exit) {
		checkDataAvailable();
	}
}

int main() {
	printf("PhyLab 2.0 v1.2\n");
	printf("© Michele Lizzit\n");
	printf("15/4/2015\n\n\n");
	fflush(stdout);

	//exit if signal received
	signal(SIGINT, sigHandler);
	signal(SIGTERM, sigHandler);
	signal(SIGSEGV, segFaultHandler);

	if (!bcm2835_init()) {
		printf("\n\nThis software is written only for bcm2835!\n\n");
		fflush(stdout);
		return 1;
	}

	printf("Starting PhyLab...\n");
	fflush(stdout);
	start();
	fflush(stdout);
	openFiles();
	createDatabase();
	loadDatabaseFromFiles();

	bool end = false;

	printf("Listening for incoming packets...\n\n");
	fflush(stdout);

	thread dataThread(checkDataThread);

	start_websocket_server();

	while (!force_exit) {
		lws_service(context, 50);
	}

	printf("Exiting...\n");
	fflush(stdout);

	dataThread.join();

	lws_context_destroy(context);
	closelog();
	closeFiles();
	printf("PhyLab terminated\n");
	fflush(stdout);
}

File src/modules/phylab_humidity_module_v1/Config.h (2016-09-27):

#define DHTTYPE DHT22

//Default CE is 8, CSN is 7
#define PIN_NRF_OVERRIDE_DEFAULT

//Uncomment if you are using a PhyLab 2.0 module
#define PCB_REV1_ATMEGA328

//PER DEBUG
  //#define centralUnitSerial Serial

#define ENABLE_HUM
#define ENABLE_TEMP

//Preset for PhyLab 2.0 modules
#ifdef PCB_REV1_ATMEGA328
  #define CE_PIN A0
  #define CSN_PIN A1
  #define SER_RX_PIN 9//3
  #define SER_TX_PIN 10//4

  #define centralUnitSerial softwareSerial

  #define DHT22_PIN 1
  #define VCC_PIN 2
  #define GND_PIN A5                                                                                                                                          
#endif

//Pins for other boards
#ifndef PCB_REV1_ATMEGA328
  //Use physical serial
  #define centralUnitSerial Serial
  #define SER_RX_PIN 3
  #define SER_TX_PIN 4

  #define DHT22_PIN 3
  #define VCC_PIN 2
  #define GND_PIN 5
#endif

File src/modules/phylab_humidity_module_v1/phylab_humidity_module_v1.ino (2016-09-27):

/*
 *  Arduino code for a PhyLab 2.0 module connected with a DHT22 humidity sensor
 *  PhyLab 2.0 - https://lizzit.it/phylab
 *  Author: Michele Lizzit - lizzit.it
 *
 *  Updates:  27/9/2016
 *  Version: 1.0
 *
 *
 *  Copyright (C) 2016  Michele Lizzit
 *
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
 *  You should have received a copy of the GNU Affero General Public License
 *  along with this program.  If not, see <http://www.gnu.org/licenses/>.
 */

#include <DHT.h>
#include <DHT_U.h>
#include <SoftwareSerial.h>
#include "Config.h"

#define SERIAL_SPEED 57600

//temperature on channel 9
//humidity on channel 6

DHT_Unified dht(DHT22_PIN, DHTTYPE);

SoftwareSerial softwareSerial(SER_RX_PIN, SER_TX_PIN); // RX, TX

bool nrfPresent;

void setup() {
  pinMode(VCC_PIN, OUTPUT);
  pinMode(GND_PIN, OUTPUT);
  digitalWrite(VCC_PIN, HIGH);
  digitalWrite(GND_PIN, LOW);
  
  centralUnitSerial.begin(SERIAL_SPEED);
  
  dht.begin();
  
  initializeNRF24L01();

  //attende 2s prima di inviare istruzioni al sensore, vedi datasheet
  //waits 2 seconds before sending commands to the sensor, see datasheet
  delay(2000);

  nrfPresent = checkPresence();
}

void loop() {
  sensors_event_t event;
  
  #ifdef ENABLE_HUM
  //SEND HUMIDITY VALUE
  {
  dht.humidity().getEvent(&event);
  int tmp = event.relative_humidity * (double)100;
  String tmp2 = String(tmp); // <= 5 chars
  
  if (tmp2.length() < 2) tmp2 = "0000" + tmp2;
  else if (tmp2.length() < 3) tmp2 = "000" + tmp2;
  else if (tmp2.length() < 4) tmp2 = "00" + tmp2;
  else if (tmp2.length() < 5) tmp2 = "0" + tmp2;
  if (tmp != 31172) {
    byte a[] = {'a', 'b', 'a', '6', 'x', 'x', 'x', 'x', 'x', '!'};
    
    a[4] = tmp2.charAt(0);
    a[5] = tmp2.charAt(1);
    a[6] = tmp2.charAt(2);
    a[7] = tmp2.charAt(3);
    a[8] = tmp2.charAt(4);
    sendDataToCentralUnit(a, 10);
  }
  else {
    byte a[] = {'a', 'b', 'a', '6', 'E', 'E', 'E', 'E', 'E', '!'};
    sendDataToCentralUnit(a, 10);
  }

  }
  #endif

  #ifdef ENABLE_TEMP
  //SEND TEMPERATURE VALUE

  {
  dht.temperature().getEvent(&event);
  int tmp = event.temperature * (double)100;
  String tmp2 = String(tmp); // <= 5 chars
  
  if (tmp2.length() < 2) tmp2 = "0000" + tmp2;
  else if (tmp2.length() < 3) tmp2 = "000" + tmp2;
  else if (tmp2.length() < 4) tmp2 = "00" + tmp2;
  else if (tmp2.length() < 5) tmp2 = "0" + tmp2;
  if (tmp != 31172) {
    byte a[] = {'a', 'b', 'a', '9', 'x', 'x', 'x', 'x', 'x', '!'};
    
    a[4] = tmp2.charAt(0);
    a[5] = tmp2.charAt(1);
    a[6] = tmp2.charAt(2);
    a[7] = tmp2.charAt(3);
    a[8] = tmp2.charAt(4);
    sendDataToCentralUnit(a, 10);
  }
  else {
    byte a[] = {'a', 'b', 'a', '9', 'E', 'E', 'E', 'E', 'E', '!'};
    sendDataToCentralUnit(a, 10);
  }

  }
  #endif
  delay(50);
}

void sendStringSerial(unsigned char packet[], short len) {
  for (short cnt = 0; cnt < len; cnt++)
    centralUnitSerial.write(packet[cnt]);
}

void sendDataToCentralUnit(unsigned char packet[], short len) {
  bool currentNrfPresent = checkPresence();
  sendStringSerial(packet, len);
  if (nrfPresent && currentNrfPresent)
    for (int cnt = 0; cnt < 3; cnt++) {
      sendStringNRF(packet, len);
      delay(150);
    }
  else if (nrfPresent && !(currentNrfPresent)) {
    nrfPresent = false;
    delay(400);
  }
  else if (!nrfPresent && currentNrfPresent) {
    initializeNRF24L01();
    nrfPresent = true;
    for (int cnt = 0; cnt < 3; cnt++) {
      sendStringNRF(packet, len);
      delay(150);
    }
  }
  else {
    delay(400);
  }
}

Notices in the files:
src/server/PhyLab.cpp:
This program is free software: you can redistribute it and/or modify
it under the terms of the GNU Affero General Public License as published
